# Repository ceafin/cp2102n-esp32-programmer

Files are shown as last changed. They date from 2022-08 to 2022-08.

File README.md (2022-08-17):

# cp2102n-esp32-programmer
CP2102N-A02 based USB-to-UART bridge controller for use in programming ESP32 chips and modules



For an interactive BOM, download and view in browser: [interactive BOM](ibom.html)

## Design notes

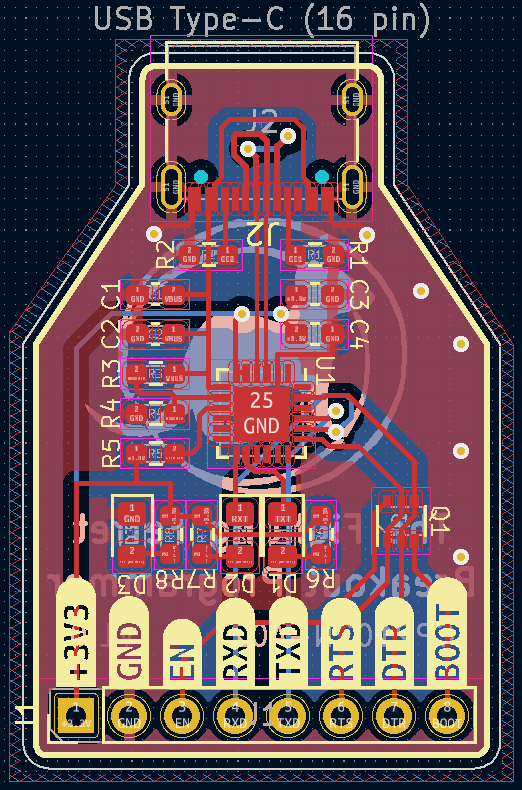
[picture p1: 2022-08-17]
pcblayout.png

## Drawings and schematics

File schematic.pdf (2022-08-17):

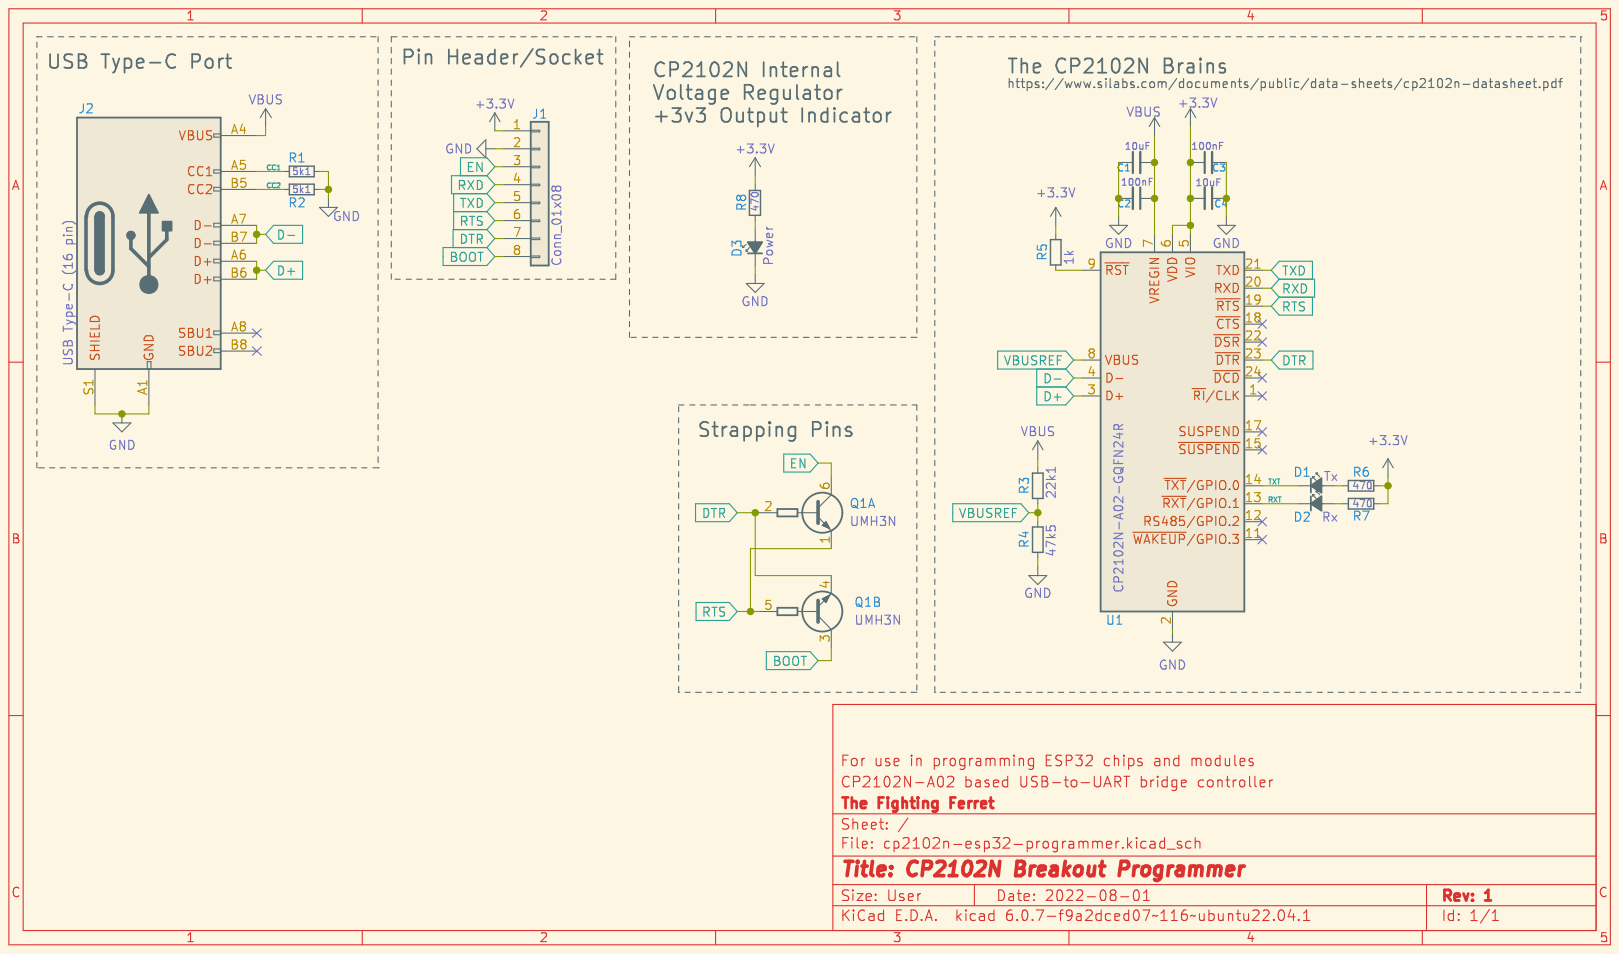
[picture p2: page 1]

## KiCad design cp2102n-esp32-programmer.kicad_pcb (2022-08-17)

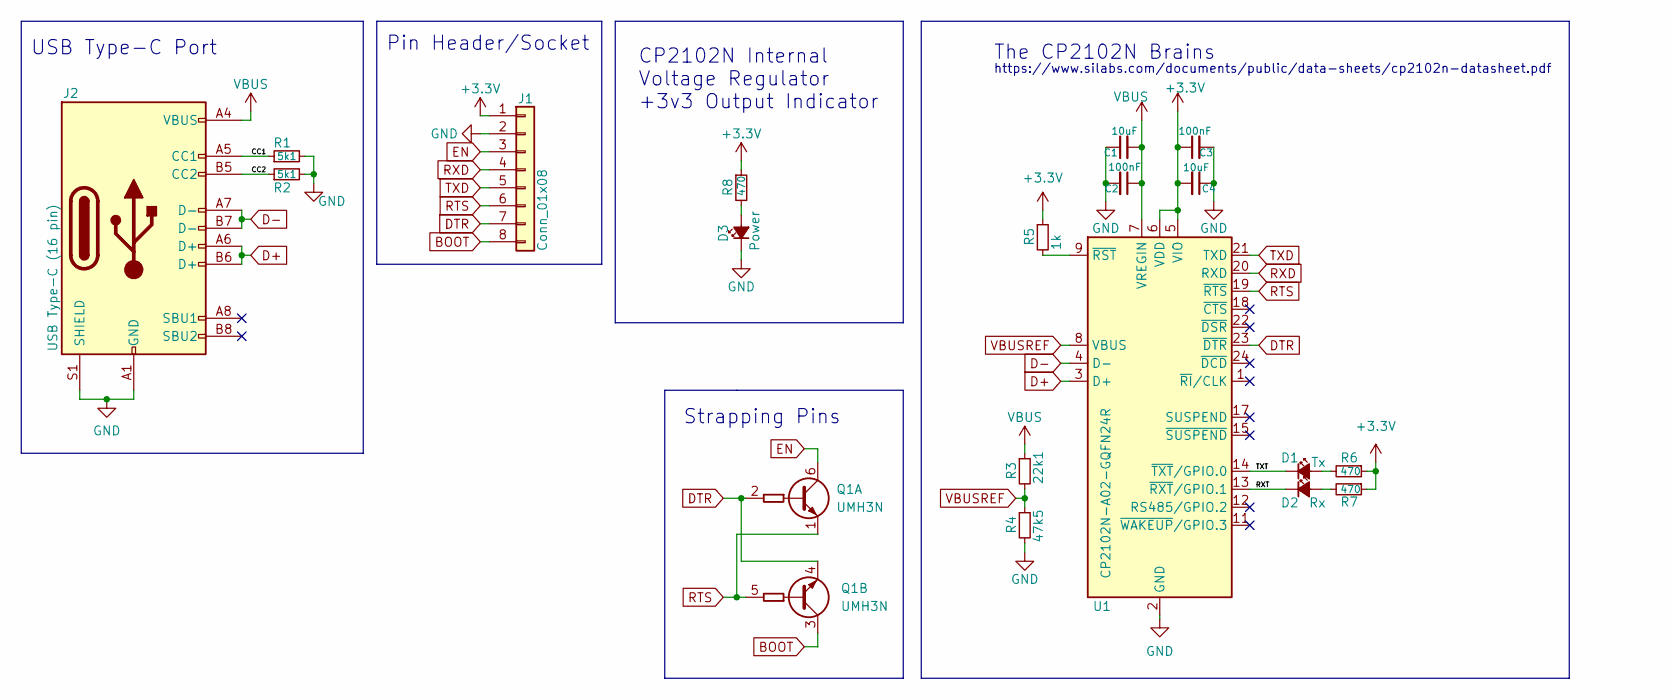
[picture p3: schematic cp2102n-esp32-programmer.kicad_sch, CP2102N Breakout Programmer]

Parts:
C1, C4: 10uF; C_0603_1608Metric_Pad1.08x0.95mm_HandSolder; LCSC Prt# C1691
C2, C3: 100nF; C_0603_1608Metric_Pad1.08x0.95mm_HandSolder; LCSC Prt# C30926
D1: Tx; LED_0805_2012Metric_Pad1.15x1.40mm_HandSolder; LCSC Prt# C84258
D2: Rx; LED_0805_2012Metric_Pad1.15x1.40mm_HandSolder; LCSC Prt# C84258
D3: Power; LED_0805_2012Metric_Pad1.15x1.40mm_HandSolder; LCSC Prt# C84256
J1: Conn_01x08; PinHeader_1x08_P2.54mm_Vertical
J2: USB Type-C (16 pin); USB_C_Receptacle_XKB_U262-16XN-4BVC11; LCSC Prt# C319148
Q1: UMH3N; SOT-363_SC-70-6; LCSC Prt# C123008
R1, R2: 5k1; R_0603_1608Metric_Pad0.98x0.95mm_HandSolder; LCSC Prt# C26000
R3: 22k1; R_0603_1608Metric_Pad0.98x0.95mm_HandSolder; LCSC Prt# C310274
R4: 47k5; R_0603_1608Metric_Pad0.98x0.95mm_HandSolder; LCSC Prt# C2933225
R5: 1k; R_0603_1608Metric_Pad0.98x0.95mm_HandSolder; LCSC Prt# C21190
R6, R7, R8: 470; R_0603_1608Metric_Pad0.98x0.95mm_HandSolder; LCSC Prt# C25241
U1: CP2102N-A02-GQFN24R; QFN-24-1EP_4x4mm_P0.5mm_EP2.6x2.6mm; LCSC Prt# C969151

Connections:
+3.3V: C3.1, C4.2, J1.1, R5.1, R6.1, R7.1, R8.1, U1.5 (VIO), U1.6 (VDD)
/CC1: J2.A5 (CC1), R1.1
/CC2: J2.B5 (CC2), R2.1
/RXT: D2.1 (K), U1.13 (~RXT/GPIO.1)
/TXT: D1.1 (K), U1.14 (~TXT/GPIO.0)
BOOT: J1.8, Q1.3 (C2)
D+: J2.A6 (D+), J2.B6 (D+), U1.3 (D+)
D-: J2.A7 (D-), J2.B7 (D-), U1.4 (D-)
DTR: J1.7, Q1.2 (B1), Q1.4 (E2), U1.23 (~DTR)
EN: J1.3, Q1.6 (C1)
GND: C1.1, C2.2, C3.2, C4.1, D3.1 (K), J1.2, J2.A1 (GND), J2.A12 (GND), J2.B1 (GND), J2.B12 (GND), J2.S1 (SHIELD), R1.2, R2.2, R4.2, U1.2 (GND), U1.25 (GND)
unnamed: D1.2 (A), R6.2
unnamed: D2.2 (A), R7.2
unnamed: D3.2 (A), R8.2
unnamed: R5.2, U1.9 (~RST)
RTS: J1.6, Q1.1 (E1), Q1.5 (B2), U1.19 (~RTS)
RXD: J1.4, U1.20 (RXD)
TXD: J1.5, U1.21 (TXD)
VBUS: C1.2, C2.1, J2.A4 (VBUS), J2.A9 (VBUS), J2.B4 (VBUS), J2.B9 (VBUS), R3.1, U1.7 (VREGIN)
VBUSREF: R3.2, R4.1, U1.8 (VBUS)

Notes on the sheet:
USB Type-C Port
https://www.silabs.com/documents/public/data-sheets/cp2102n-datasheet.pdf
Pin Header/Socket
CP2102N Internal Voltage Regulator +3v3 Output Indicator
Strapping Pins
The CP2102N Brains

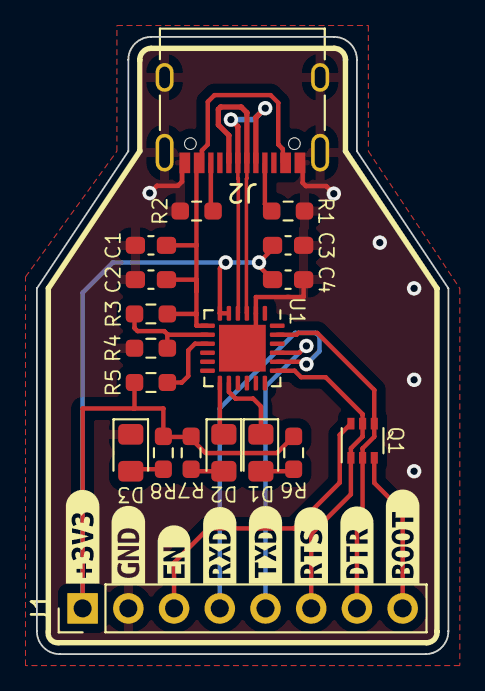
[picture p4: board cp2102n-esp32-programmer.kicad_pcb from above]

Board: 2 copper layers, 22.9 x 34.3 mm, 27 parts (0 on the bottom side), 20 nets.

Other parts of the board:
kibuzzard-62E5E2EC: G***; kibuzzard-62E5E2EC
kibuzzard-62E5E2FE: G***; kibuzzard-62E5E2FE
kibuzzard-62E5E3A7: G***; kibuzzard-62E5E3A7
kibuzzard-62E5E34B: G***; kibuzzard-62E5E34B
kibuzzard-62E5E36B: G***; kibuzzard-62E5E36B
kibuzzard-62E5E308: G***; kibuzzard-62E5E308
kibuzzard-62E5E316: G***; kibuzzard-62E5E316
kibuzzard-62E5E325: G***; kibuzzard-62E5E325

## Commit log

2022-08-17 Adding PCB and Schematic
    [cp2102n-esp32-programmer.kicad_pcb, cp2102n-esp32-programmer.kicad_sch]
2022-08-17 adding schematic PDF
2022-08-17 adding pcb layout PNG
2022-08-17 adding interactive BOM HTML

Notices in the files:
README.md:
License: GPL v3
